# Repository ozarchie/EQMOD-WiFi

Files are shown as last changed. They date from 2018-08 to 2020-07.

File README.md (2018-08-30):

# EQMOD-WiFi
An ESP8266 based WiFi to serial, WiFi to UDP, tested on an EQ6 mount

## Introduction
This project describes a WiFi interface used between the EQMOD/SynScanPro software and the DB9 TTL serial interface connector on the Skywatcher EQ6 mount.

## EQMOD - Serial  

The EQMOD serial interface needs two WeMos ESP8266 devices - one at the host end and one at the mount end. ESP_NOW protocol is used to ensure the connection is fast.  
The WeMos device firmware uses ESP_NOW protocol to receive and send the data from/to the EQMOD serial port. At the mount interface, it sends and receives at 3.3v level to/from the EQ6.  

## SynScanPro - UDP  

On a Windows/Mac/Android/Apple device, you can use the mount interface in the SynScanPro app. By selecting UDP mode, the mount will work in either access point (mount is an AP) or station (mount joins the local network) modes.  
UDP mode and AP/STA modes are selected by jumpers/switches on the mount interface.  
In station mode, the ssid and password needs to be changed in the firmware. Later revisions may include the ability to do this OTA.  
The SynScanPro interface uses UDP to send and receive data to and from the WeMos device. The WeMos device sends and receives the data at 3v3 level to the EQ6 mount.  

It has only been tested on the EQ6 mount.  
In theory, any host system that sends/receives the EQMOD serial data stream via UDP will work with the mount device.  

## Software

The software is in the DualDevice directory.  
ESP28266SerialServer is the firmware for the mount interface.  
ESP28266SerialClient is the firmware for the host serial inetrface.  
The software can only be classed as an alpha release as it has only been tested by me on my EQ6 V2.04 mount.  

## Notices
This interface uses sample code from several ESP8266 arduino repositories.  
There are numerous HowTo videos and support groups for ESP8266.    
Sample circuits are described, but and araduino based ESP8266 is the simplest approach.  
  
**Some WeMos devices have problems downloading. Search the discussion groups first.**   

*I use genuine WeMos devices and have not experienced the reported issues, which presumably come from copycat devices. I also use Visual Studio for arduino development which may use different download software and interfaces.* 

Below are the Fritzing schematics and breadboard. Take care as I have not verified it, but it follows my prototype.  

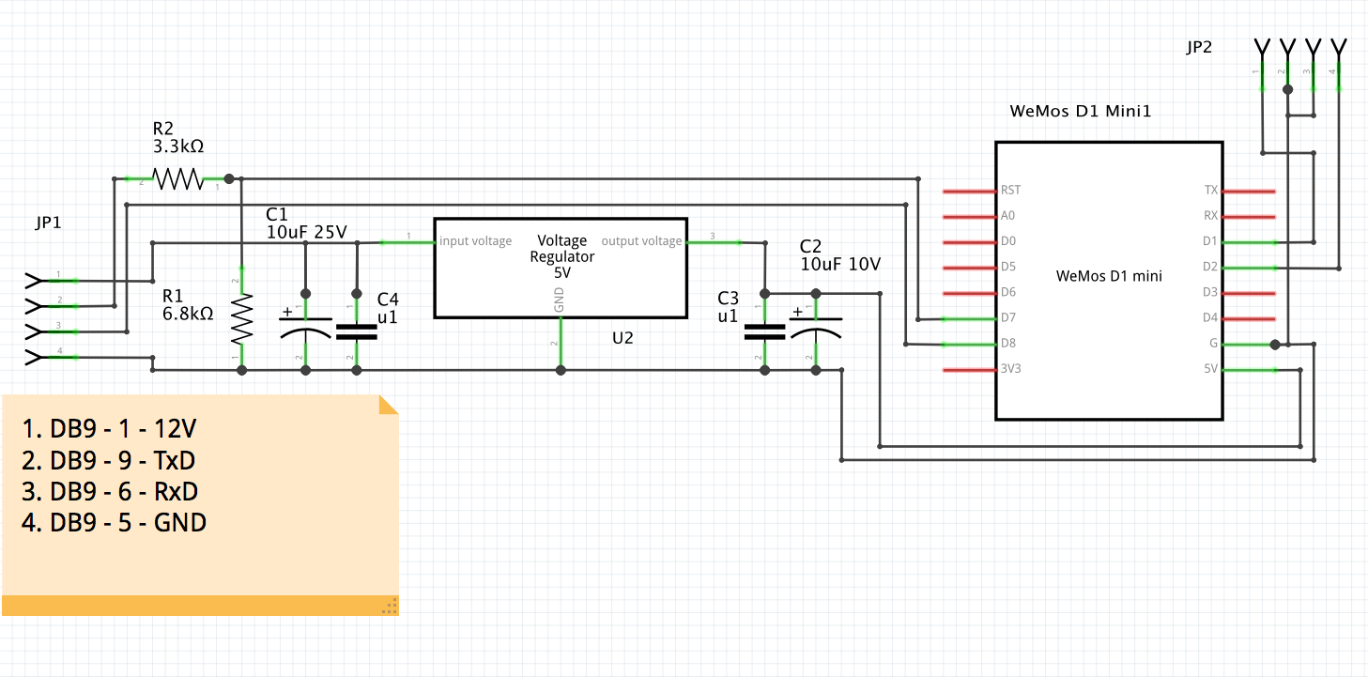
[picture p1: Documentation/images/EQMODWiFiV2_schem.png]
Schematic
 
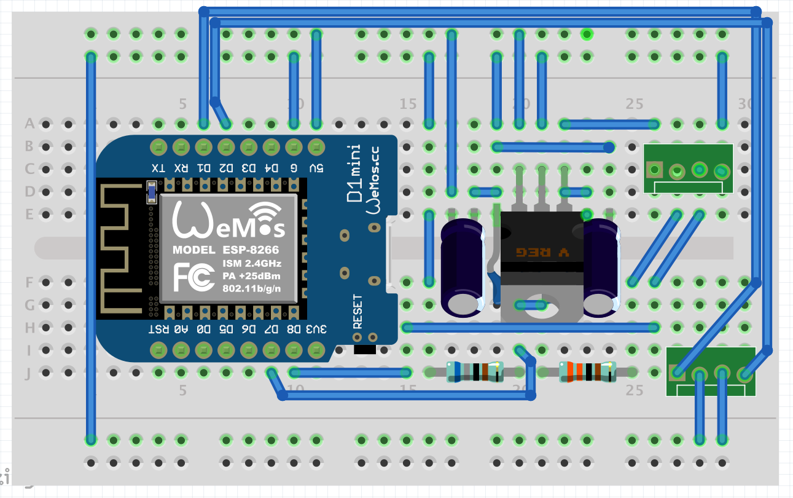
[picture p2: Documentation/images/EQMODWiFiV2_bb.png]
Breadboard


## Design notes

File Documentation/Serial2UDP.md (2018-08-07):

# Setup

**Not working yet**
*When the EQMOD WiFi adapter starts up, it sets it up in Station mode and tries to connect to a previously saved Access Point. If this is unsuccessful (or if no previous network has been saved) it changes the EQMOD WiFi adapter into Access Point mode and starts up a DNS and WebServer at default IP address “192.168.4.1”.*

*In Access Point mode, the user device (iOS, Android, or Windows) can connect to that WiFi network, using the ssid of “EQMOD” and password of “shillito”. [You can change this in the code]. It will then get its IP address assigned. By pointing the browser to “192.168.4.1”, the user can access a web page that will allow the user to set the users’ own wireless network configuration (ssid, password).*

The WiFi adapter uses the default ssid/pass to connect to a user network. This can be changed from the default in the code.  
Once saved, the EQMOD WiFi adapter will restart and log onto the users’ network in Station mode.  

# SynScanPro

## Introduction 

The SynScanPro application detects the EQMOD WiFi adapter by talking to UDP port 11880. The EQMOD WiFi adapter listens on UDP port 11880 and forwards the received data to the mount serial port at 9600 baud. It listens for the serial (9600 baud) response from the mount and forwards that data to the UDP port that it received the initial data from. An internal virtual serial port at 9600 baud has been established. It is a simple UDP-based IP-to-serial bridge.

The SynScanPro Application needs to be setup. This is done via the Settings screen.
## Windows app notes

1. [Startup](https://github.com/ozarchie/EQMOD-WiFi/blob/master/Documentation/images/EQMODWiFiWin-1.PNG)  
2. [Settings](https://github.com/ozarchie/EQMOD-WiFi/blob/master/Documentation/images/EQMODWiFiWin-2.PNG)  
3. [UDP Screen](https://github.com/ozarchie/EQMOD-WiFi/blob/master/Documentation/images/EQMODWiFiWin-3.PNG)  
4. [Connect](https://github.com/ozarchie/EQMOD-WiFi/blob/master/Documentation/images/EQMODWiFiWin-4.PNG)  
5. [Connecting](https://github.com/ozarchie/EQMOD-WiFi/blob/master/Documentation/images/EQMODWiFiWin-5.PNG)  
6. [Connected](https://github.com/ozarchie/EQMOD-WiFi/blob/master/Documentation/images/EQMODWiFiWin-6.PNG)  
7. [Error Screen](https://github.com/ozarchie/EQMOD-WiFi/blob/master/Documentation/images/EQMODWiFiWin-7.PNG)  

Select settings from the main screen.

## Android app notes
1. [Startup](https://github.com/ozarchie/EQMOD-WiFi/blob/master/Documentation/images/EQMODWiFiAndroid-1.png) 
2. [Settings](https://github.com/ozarchie/EQMOD-WiFi/blob/master/Documentation/images/EQMODWiFiAndroid-2.png) 
3. [Reveal Connection Settings](https://github.com/ozarchie/EQMOD-WiFi/blob/master/Documentation/images/EQMODWiFiAndroid-3.png) 
4. [UDP Screen](https://github.com/ozarchie/EQMOD-WiFi/blob/master/Documentation/images/EQMODWiFiAndroid-4.png) 
5. [Connect](https://github.com/ozarchie/EQMOD-WiFi/blob/master/Documentation/images/EQMODWiFiAndroid-5.png) 
6. [Connecting](https://github.com/ozarchie/EQMOD-WiFi/blob/master/Documentation/images/EQMODWiFiAndroid-6.png) 
7. [Connected Warning](https://github.com/ozarchie/EQMOD-WiFi/blob/master/Documentation/images/EQMODWiFiAndroid-7.png) 
8. [Connected](https://github.com/ozarchie/EQMOD-WiFi/blob/master/Documentation/images/EQMODWiFiAndroid-8.png) 

Note2: Tapping the blank line between "Wi-Fi Setting" and "Help" under "settings " eight times. Scroll up and down and it will show extra line "Connect Settings" under "Help"

## Needs confirmation on Apple.

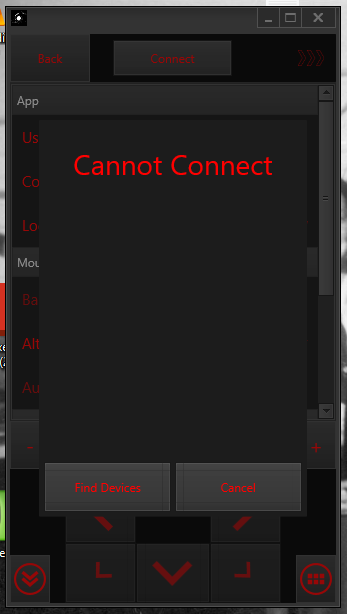
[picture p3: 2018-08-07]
Documentation/images/EQMODWiFiWin-7.PNG

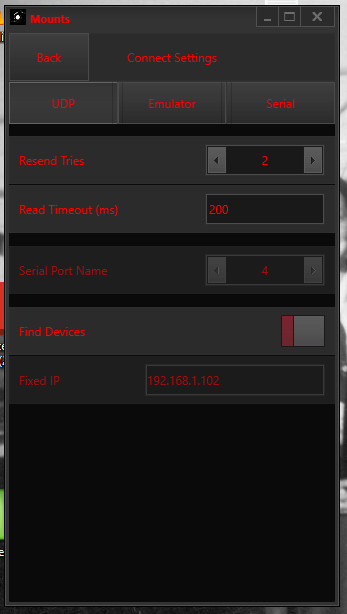
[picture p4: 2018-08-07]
Documentation/images/EQMODWiFiWin-3.PNG

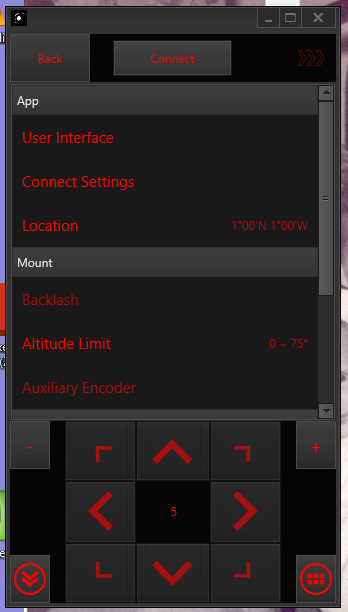
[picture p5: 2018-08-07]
Documentation/images/EQMODWiFiWin-2.PNG

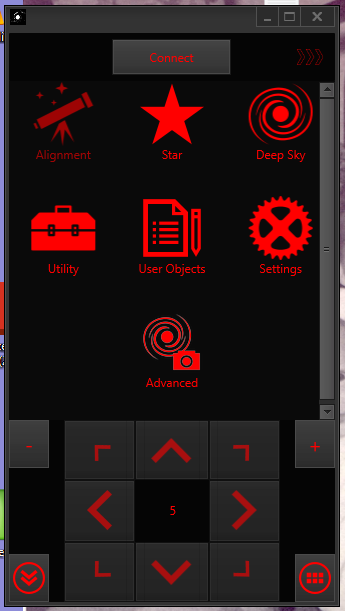
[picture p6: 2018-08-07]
Documentation/images/EQMODWiFiWin-1.PNG

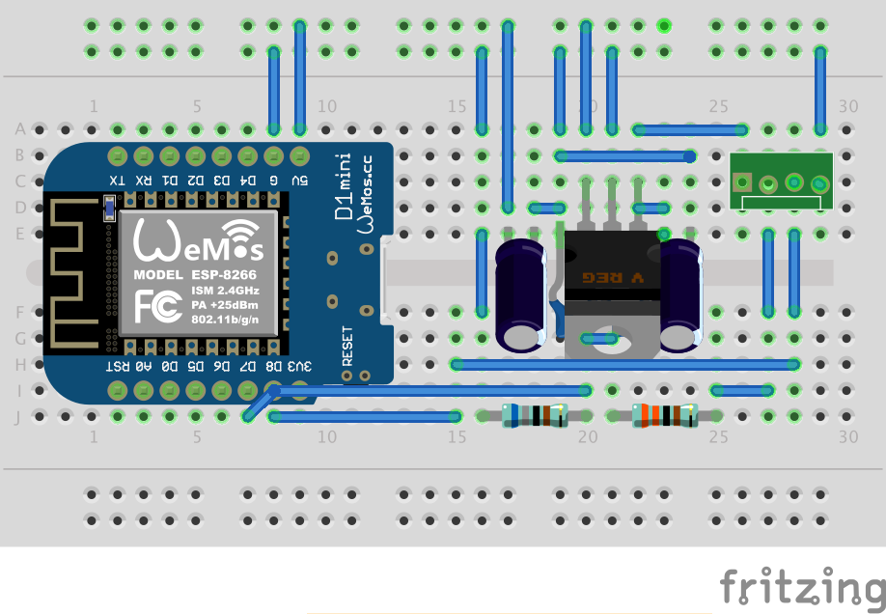
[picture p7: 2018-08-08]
Documentation/images/EQMODWiFi_bb.png

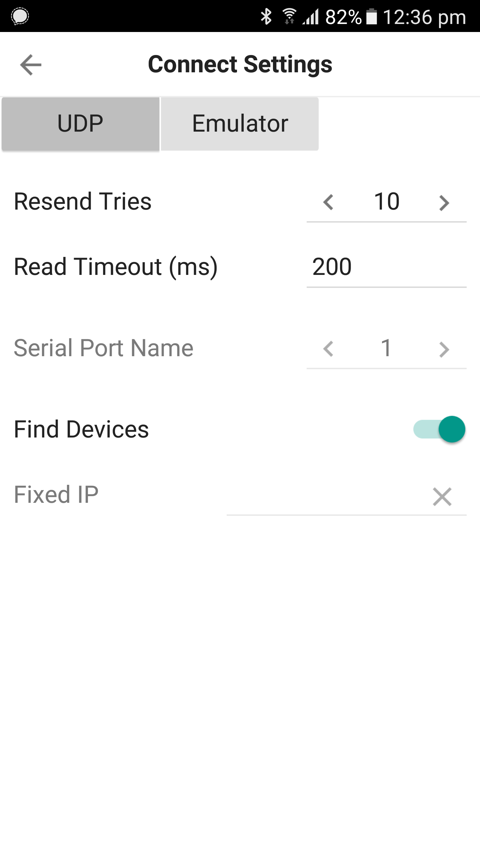
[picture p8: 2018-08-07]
Documentation/images/EQMODWiFiAndroid-4.png

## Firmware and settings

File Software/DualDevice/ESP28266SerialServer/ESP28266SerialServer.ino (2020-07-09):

// ESP2SerialServer.ino V0.1
// https://esp-idf.readthedocs.io/en/latest/api-reference/wifi/esp_now.html

#include <ESP8266WiFi.h>
#include <WiFiUdp.h>
#include <TimeLib.h>              //https://github.com/PaulStoffregen/Time
#include <TimeAlarms.h>           //https://github.com/PaulStoffregen/TimeAlarms
#include "myesp_now.h"

extern "C" {
#include <espnow.h>
#include <user_interface.h>
}

uint8_t smac[] = { 0x5C, 0xCF, 0x7F, 0x88, 0x88, 0x88 };		// Hopefully :) Unique Espressif mac
uint8_t mmac[] = { 0x5C, 0xCF, 0x7F, 0x00, 0x00, 0x00 };		// Master mac address
const uint8_t WIFI_CHANNEL = 4;

char *ssid = "EQMODWiFi";
char *pass = "CShillit0";
IPAddress ip(192, 168, 88, 1);
IPAddress netmask(255, 255, 255, 0);

WiFiUDP udp;
IPAddress remoteIp;
const int localUdpPort = 11880;

struct __attribute__((packed)) DataStruct {
    char text[255];
	uint8_t len;
};

DataStruct sendWiFi;
DataStruct recvWiFi;
uint8_t sendWiFi8[sizeof(sendWiFi)];
uint8_t recvWiFi8[sizeof(recvWiFi)];

#define EQMOD_BAUD 9600
#define DEBUG_BAUD 9600
#define EQxTimeout 10
#define EQxSize ESP_NOW_MAX_DATA_LEN-1

#define dbgSerial Serial1
#define EQxSerial Serial
#define PROTOCOL 5       // GPIO5
#define MODE 4           // GPIO4
#define LED 14           // GPIO14

uint8_t RxD;
uint8_t TxD;

unsigned long RxTimeout;
unsigned long WiFiTimeout;
unsigned long LastmS;
unsigned long CheckmS = 1000;
bool Connected = false;
bool dataSending = false;
bool waitingForReply = false;

unsigned long TxDuS;
unsigned long AckuS;
unsigned long RxDuS;

unsigned long LastLEDmS;
unsigned long FastLEDmS = 200;
unsigned long SlowLEDmS = 800;
unsigned long BlinkmS = SlowLEDmS;
unsigned long SavedBlinkmS = SlowLEDmS;

bool UDPFlag = false;
bool APFlag = false;

void initVariant() {
  WiFi.mode(WIFI_AP);
  wifi_set_macaddr(SOFTAP_IF, &smac[0]);
}

// Init ESP Now with fallback
void InitESPNow() {
  WiFi.disconnect();
  if (esp_now_init() == ESP_OK) {
    dbgSerial.println("ESPNow Init Success");
  }
  else {
    dbgSerial.println("ESPNow Init Failed");
    // Retry InitESPNow, add a counte and then restart?
    // InitESPNow();
    // or Simply Restart
    ESP.restart();
  }
}

// Receive data from ESP_NOW
void recvCallBack(uint8_t *senderMac, uint8_t *incomingData, uint8_t len) {
// Indicating incoming data
  BlinkmS = FastLEDmS;
  
// Get local copy
  memcpy(&recvWiFi.text, incomingData, len);      // Receive data from EQMOD Tx
  recvWiFi.text[len] = 0;                         // Null terminate
  recvWiFi.len = len;
  waitingForReply = false;
  
// Check if serial requesting restart
  if ((len == 20) && ((strncmp(recvWiFi.text, "Mount, please reply", 15) == 0))) {
    // Data should not be copied to mount
    recvWiFi.len = 0;
    Connected = false;
    dataSending = false;
    // Reply to reconnect request
    strcpy(sendWiFi.text, "EQMOD Mount V1.0\n");
    sendWiFi.len = sizeof("EQMOD Mount V1.0\n");
    dbgSerial.println("Reconnecting");
    sendData(senderMac);       // Copy data to EQMOD Rx
    return;
  }
  if (!Connected) {               // Capture the serial mac address
    for (byte n = 0; n < 6; n++) {
      mmac[n] = senderMac[n];
    }
  }
}

// Send data to ESP_NOW
void sendData(uint8_t *macAddr) {
// Indicating outgoing data (either mount serial data, or connection response)
    BlinkmS = FastLEDmS;
// If first time, create a peer2peer connection with the sender mac address
  if (!Connected) {
    esp_now_add_peer(macAddr, ESP_NOW_ROLE_COMBO, WIFI_CHANNEL, NULL, 0); // Only one paired device - the first one to respond
  }
  
// Send data, if not waiting for previous send to complete
  if (!dataSending) {
    memcpy(sendWiFi8, &sendWiFi, sendWiFi.len);     // Need to satisfy esp_now
    esp_now_send(NULL, sendWiFi8, sendWiFi.len);    // NULL means send to all peers
    dataSending = true;
  }  
}

// Get Send data status
void sendCallBack(uint8_t* mac, uint8_t sendStatus) {
  if (sendStatus == 0) {
    sendWiFi.len = 0;         // Data successfully sent
    BlinkmS = SlowLEDmS;      // Data complete, so back to slow blink
    Connected = true;
    dataSending = false;
    waitingForReply = true;
  }
  else {
    BlinkmS = FastLEDmS;    // Still waiting
  }
}

// Send received WiFi (UDP/ESP_NOW) data to the mount serial data
// Data in recvWiFi.text, length recvWiFi.len
void putMountSerialData(void) {
  uint8_t TxD, n;
  n = 0;
  while (n < recvWiFi.len) {
    TxD = recvWiFi.text[n];
    EQxSerial.write(TxD);
    dbgSerial.write(TxD);
    n += 1;
  }
  recvWiFi.len = 0;   // All data sent
  BlinkmS = SlowLEDmS;
}

// Get mount serial data to send to WiFi (UDP/NOW)
// Data in sendWiFi.text, length sendWiFi.len
void getMountSerialData(void) {
  uint8_t RxD, n;
// Indicate outgoing mount data
  BlinkmS = FastLEDmS;

// Receive mount serial data, with timeout
  LastmS = millis();
  RxTimeout = 0;
  RxD = 0;
  n = 0;
  sendWiFi.text[0] = 0;
  
  // Wait for '=' or '!'
  while ((RxTimeout < EQxTimeout) && (RxD != '=') && (RxD != '!')) {
    RxTimeout = millis() - LastmS;
    if (EQxSerial.available()) {
      LastmS = millis();
      RxD = EQxSerial.read();
    }
  }
  if (RxTimeout < EQxTimeout) {
    sendWiFi.text[n] = RxD;
    dbgSerial.write(RxD);
    n += 1;
  }
  LastmS = millis();
  RxTimeout = 0;  
  // Continue reading until CR
  while ((RxTimeout < EQxTimeout) && (RxD != 0x0d)) {
    RxTimeout = millis() - LastmS;
    if (EQxSerial.available()) {
      LastmS = millis();
      RxD = EQxSerial.read();
      dbgSerial.write(RxD);
      sendWiFi.text[n] = RxD;
      n += 1;
    }
  }
  sendWiFi.text[n] = 0;
  sendWiFi.len = n;     // Length of Rx data
}

void blinkLed() {
    digitalWrite(LED, !digitalRead(LED));
    if (SavedBlinkmS != BlinkmS) {
      Alarm.timerRepeat(BlinkmS, blinkLed);
      SavedBlinkmS = BlinkmS;
    }
}

// ================================================================================================

void setup() {

  pinMode(LED, OUTPUT);             // LED indicator
  pinMode(PROTOCOL, INPUT_PULLUP);  // ESP_NOW(1),  UDP(0)
  pinMode(MODE, INPUT_PULLUP);      // AP(1),       STA(0)
  
  EQxSerial.begin(EQMOD_BAUD);      // Pins Tx(01), Rx(03) (USB)
  EQxSerial.swap();                 // Pins D8(15), D7(13) (TTL)
  dbgSerial.begin(DEBUG_BAUD);      // Pin  D4( 2)
  
  dbgSerial.println("");
  dbgSerial.print("digitalRead(PROTOCOL): ");
  dbgSerial.println(digitalRead(PROTOCOL));
  dbgSerial.print("digitalRead(MODE)    : ");
  dbgSerial.println(digitalRead(MODE));
  
  if (digitalRead(PROTOCOL))
    UDPFlag = false;
  else
    UDPFlag = true;

  if (digitalRead(MODE))
    APFlag = true;
  else
    APFlag = false;
    
  if (APFlag) { 
  // AP mode       device connects directly to EQMODWiFi) (no router)
  // For AP mode:  UDP2Serial: This ESP assigns IP addresses
  // For AP mode:  ESP IP is always 192.168.88.1 (set above)
    dbgSerial.println("Access Point Mode");
    strcpy(ssid, "EQMODWiFi");          // Default EQMOD
    strcpy(pass, "CShillit0");
  	WiFi.mode(WIFI_AP);
  	WiFi.softAPConfig(ip, ip, netmask); // softAP ip
  	WiFi.softAP(ssid, pass);            // softAP ssid, pass
  }
  else {
  // STA mode       EQMODWiFi connects to network router and gets an IP
  // For STA mode:  Host software must detect that IP
  // For STA mode:  UDP2Serial router network assigns IP address
    dbgSerial.println("Station Mode");
    strcpy(ssid, "EQMODnet");      	// "YourSSID";
    strcpy(pass, "EQMODpwd");  		// "YourPass";
  	WiFi.mode(WIFI_STA);
  	WiFi.begin(ssid, pass);
  	while (WiFi.status() != WL_CONNECTED) {
  		delay(100);
      dbgSerial.print(".");
  	}
    dbgSerial.println(" connected");
  }
  
  if (!UDPFlag) {
  // ESP_NOW mode   (EQMODWiFi responds to MAC protocol)
    dbgSerial.println("ESP_NOW Mode");
    InitESPNow();
    dbgSerial.println("ESPNOW2SerialServer");
    dbgSerial.print("Mount soft  mac: "); dbgSerial.println(WiFi.softAPmacAddress());
  	dbgSerial.print("Mount hard  mac: "); dbgSerial.println(WiFi.macAddress());
  	esp_now_set_self_role(ESP_NOW_ROLE_COMBO);
  	esp_now_register_recv_cb(recvCallBack);	
  	esp_now_register_send_cb(sendCallBack);
  }
  else {
    dbgSerial.println("UDP Mode");
    udp.begin(localUdpPort);
    dbgSerial.println("UDP2SerialServer");
    if (APFlag) 
      dbgSerial.printf("Now listening at IP %s, UDP port %d\n", WiFi.softAPIP().toString().c_str(), localUdpPort);
    else
      dbgSerial.printf("Now listening at IP %s, UDP port %d\n", WiFi.localIP().toString().c_str(), localUdpPort);
  }
	sendWiFi.len = 0;
  recvWiFi.len = 0;
  Alarm.timerRepeat(BlinkmS, blinkLed);
}

// -------------------------------------------------------------------------------------------

void loop() {
  if (UDPFlag) {
    recvWiFi.len = udp.parsePacket();
    if (recvWiFi.len > 0) {
      // receive incoming UDP packets
      recvWiFi.len = udp.read(recvWiFi.text, 250);
      if (recvWiFi.len > 0) {
        recvWiFi.text[recvWiFi.len] = 0;
//        dbgSerial.print("RxUDP - len: ");
//        dbgSerial.print(recvWiFi.len);
//        dbgSerial.print(", data: ");
//        dbgSerial.println(recvWiFi.text);
      }
      // Send data to mount
      putMountSerialData();
      
      // Get data from mount
      getMountSerialData();
  
      // send back a reply, to the IP address and port we got the packet from
      if (sendWiFi.len > 0) {
//        dbgSerial.print("TxUDP - len: ");
//        dbgSerial.print(sendWiFi.len);
//        dbgSerial.print(", data: ");
//        dbgSerial.println(sendWiFi.text);
        udp.beginPacket(udp.remoteIP(), udp.remotePort());
        udp.write(sendWiFi.text, sendWiFi.len);
        udp.endPacket();
      }
      sendWiFi.len = 0;
    }    
  }
  else {
  	if (Connected) {
  		if (EQxSerial.available() > 0) 
  		  getMountSerialData();			// Receive data from Mount Tx
  		if (sendWiFi.len > 0)
  			sendData(mmac);				// Copy data to EQMOD Rx
  		if (recvWiFi.len > 0)		// Received data from EQMOD Tx
  			putMountSerialData();		// Copy data to Mount Rx
  	}
  }
}

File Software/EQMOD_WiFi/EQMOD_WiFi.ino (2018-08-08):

// Visual Micro is in vMicro>General>Tutorial Mode
// 
/*
    Name:       EQMOD_WiFi.ino
    Created:	2018-08-06 11:28:57 AM
    Author:     JOHNWIN10PRO\John
*/

// Define User Types below here or use a .h file
//


// Define Function Prototypes that use User Types below here or use a .h file
//


// Define Functions below here or use other .ino or cpp files
//

#include <ESP8266WiFi.h>
#include <WiFiUdp.h>
#include <SoftwareSerial.h>

#define UART_BAUD 9600
#define EQ6_BAUD 9600
#define packetTimeout 20 // ms (if nothing more on UART, then send packet)
#define bufferSize 8192

const char* APNAME = "EQMODWiFi";
const char* APPASSWORD = "Shillit0";

//WiFiManager wifiManager;
WiFiUDP Udp;

const int localUdpPort = 11880;     // local port to listen on
char incomingPacket[255];           // buffer for incoming packets

SoftwareSerial swSerial1(13, 15, false, 256);
uint8_t replyPacket[bufferSize];
uint16_t replyLen = 0;

void setup()
{
	Serial.begin(UART_BAUD); // USB Serial
	//  Serial.swap();
	Serial.flush();
	swSerial1.begin(EQ6_BAUD); // EQ6 Serial
	swSerial1.flush();

	WiFi.mode(WIFI_STA);
	Serial.printf("Connecting to %s ", APNAME); // USB Serial
	WiFi.begin(APNAME, APPASSWORD);

	while (WiFi.status() != WL_CONNECTED)
	{
		delay(500);
		Serial.print(".");
	}
	Serial.println(" connected"); // USB Serial

	Udp.begin(localUdpPort);
	Serial.printf("Now listening at IP %s, UDP port %d\n", WiFi.localIP().toString().c_str(), localUdpPort); // USB Serial
}

void loop()
{
	int packetSize = Udp.parsePacket();
	if (packetSize > 0)
	{
		// receive incoming UDP packets
		Serial.printf("Received %d bytes from %s, port %d\n", packetSize, Udp.remoteIP().toString().c_str(), Udp.remotePort()); // USB Serial
		int packetLen = Udp.read(incomingPacket, 255);
		if (packetLen > 0)
		{
			incomingPacket[packetLen] = 0;
		}
		// Send to EQ6
		swSerial1.write(incomingPacket, packetLen);
		//  and copy to console
		Serial.printf("UDP packet contents >>> %d,  %s\n", packetLen, incomingPacket); // USB Serial

		// initialize reply pointer (also length)
		replyLen = 0;
		// Read the EQ6 data until pause
		while (1) {
			if (swSerial1.available()) {
				replyPacket[replyLen] = (char)swSerial1.read(); // read char from EQ6
				if (replyLen < (bufferSize - 1)) replyLen++;
				yield();
			}
			else {
				delay(packetTimeout);
				if (!swSerial1.available()) {
					break;
				}
			}
		}
		replyPacket[replyLen] = 0;

		// send back a reply, to the IP address and port we got the packet from
		if (replyLen > 0) {
			Udp.beginPacket(Udp.remoteIP(), Udp.remotePort());
			Udp.write(replyPacket, replyLen);
			Udp.endPacket();
			Serial.printf("Sent  %d bytes >>>  %s to %s, port %d\n", replyLen, replyPacket, Udp.remoteIP().toString().c_str(), Udp.remotePort()); // USB Serial
		}
	}
}

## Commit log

2018-08-06 Beginning of EQMOD_WiFi
    Currently, only fixed ssid/pass
    [EQMODWiFi.fzz]
2018-08-08 Initial schematic
2018-08-30 Change to two WeMos devices, still ESP826
2018-08-30 Update for dual device operation.
2020-07-09 Update ESP28266SerialServer.ino
    Update esp8266 as well as new ESP32
